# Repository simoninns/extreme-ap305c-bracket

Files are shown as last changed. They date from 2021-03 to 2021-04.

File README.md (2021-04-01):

# Extreme-AP305C-Bracket

## Overview
This project provides a 3D printable bracket for the Extreme Networks AP305C, AP410C and AP510C (aka Aerohive AP650) access points. 

Note: This project is GPLv3 open-source. The github repository for the model (containing the complete OpenSCAD project) can be found at https://github.com/simoninns/extreme-ap305c-bracket

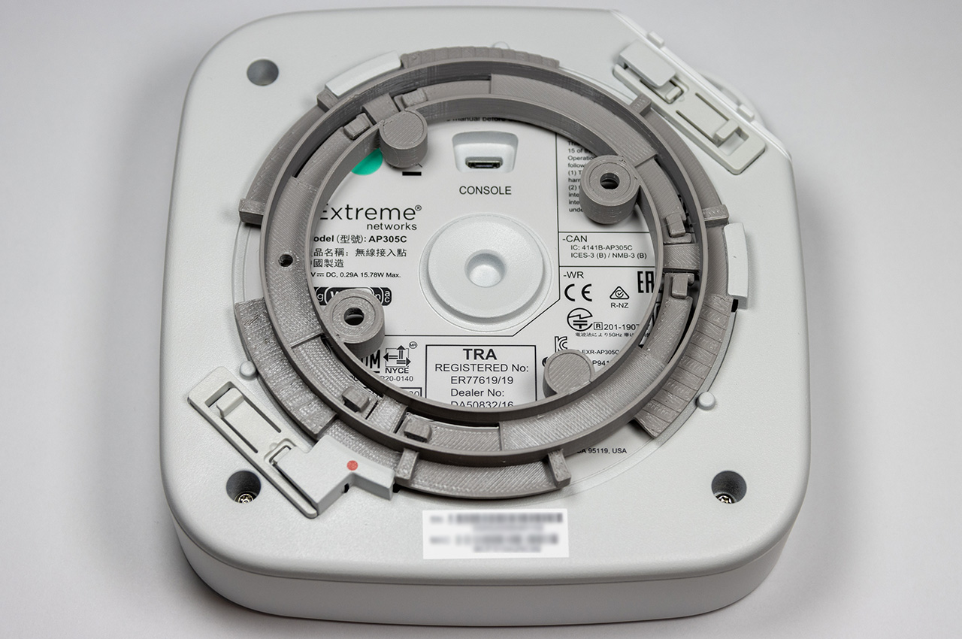
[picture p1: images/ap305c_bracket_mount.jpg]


The bracket provides two mounting points for wall or ceiling mounting using two screws (with appropriate wall plugs) which should be 3mm in diameter with 6mm flat heads.

The bracket can also be used as a desk stand for the access points (to prevent scratching of desks and other surfaces).  Attach 4x 8mm 3M Bump-on feet to the 4 marked areas to keep the bracket steady and prevent surface damage.  When used as a desk stand the bracket does not cover the console cable connector on the base of the access point.

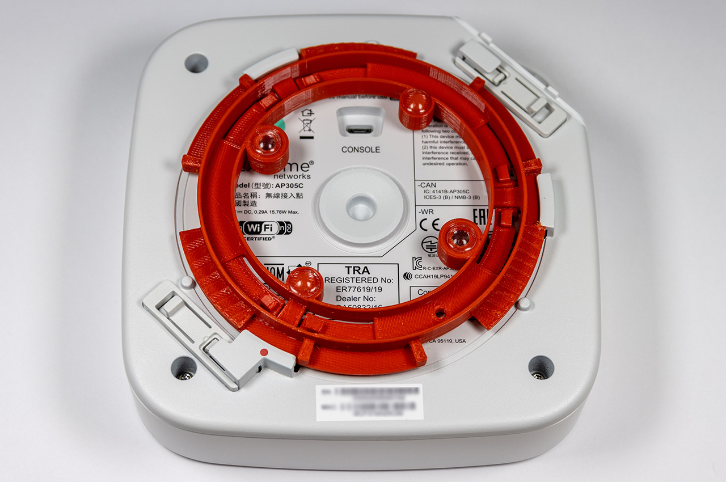
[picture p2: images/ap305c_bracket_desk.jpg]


Note that the centre line of the AP is shown as two dashes for the cable-side and one dash for the opposite.  This marked line is to assist with aligning the bracket so the network cable output is in the correct place when the bracket is orientated with the red dot on the AP.

## Printing instructions
The model has been printed and tested on the Prusa MK3S/MMU2S printer using PETG filament. All parts fit on a 20x20 printing bed.

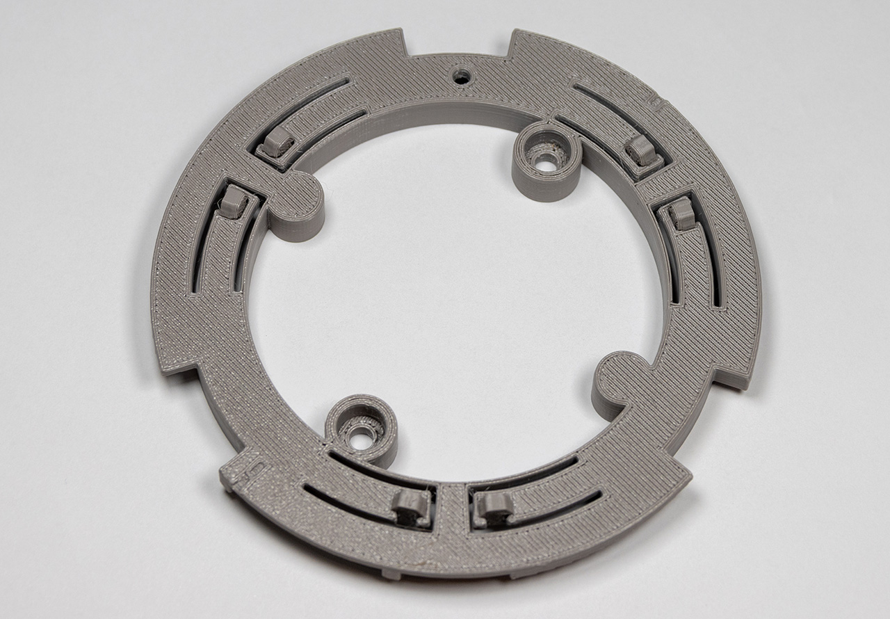
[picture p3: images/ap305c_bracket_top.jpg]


### Recommended print settings

* Material: PETG
* Layer: 0.20mm (Quality)
* Infill: 15%
* Supports: Support on build plate only
* Print time (approximate): 1h 52m

## Assembly
Place each one of the lever bumps into the lever recess sideways through the provided gap.  Twist lever bump through 90 degrees.  The bump should lock into place.  This is easier if you use a pair of small flat-nosed pliers (be careful not to squeeze the pieces too hard when handling with the pliers).

## Attaching and detaching from the AP
If the bracket is wall or ceiling mounted press down on the AP and rotate clockwise to attach and counter clockwise to detach.  If using the bracket as a desk-mount simply hold the AP in your left hand and press your right palm into the bracket to keep it flat, then rotate.

## Author
The Extreme Networks AP305C bracket is designed and maintained by Simon Inns.

## Disclaimer

Please note that this bracket is the personal work of the author.  This bracket is not associated with nor endorsed by Extreme Networks.

# Licensing

## OpenSCAD source files - software license (GPLv3)

    This is free software: you can redistribute it and/or modify
    it under the terms of the GNU General Public License as published by
    the Free Software Foundation, either version 3 of the License, or
    (at your option) any later version.
    
    This program is distributed in the hope that it will be useful,
    but WITHOUT ANY WARRANTY; without even the implied warranty of
    MERCHANTABILITY or FITNESS FOR A PARTICULAR PURPOSE.  See the
    GNU General Public License for more details.
    
    You should have received a copy of the GNU General Public License
    along with this program.  If not, see <http://www.gnu.org/licenses/>.

## Non-source-code media - Creative Commons license (Creative Commons BY-SA 4.0)

Please see the following link for details: https://creativecommons.org/licenses/by-sa/4.0/

You are free to:

Share - copy and redistribute the material in any medium or format
Adapt - remix, transform, and build upon the material
for any purpose, even commercially.

This license is acceptable for Free Cultural Works.

The licensor cannot revoke these freedoms as long as you follow the license terms.

Under the following terms:

Attribution - You must give appropriate credit, provide a link to the license, and indicate if changes were made. You may do so in any reasonable manner, but not in any way that suggests the licensor endorses you or your use.

ShareAlike - If you remix, transform, or build upon the material, you must distribute your contributions under the same license as the original.

No additional restrictions - You may not apply legal terms or technological measures that legally restrict others from doing anything the license permits.

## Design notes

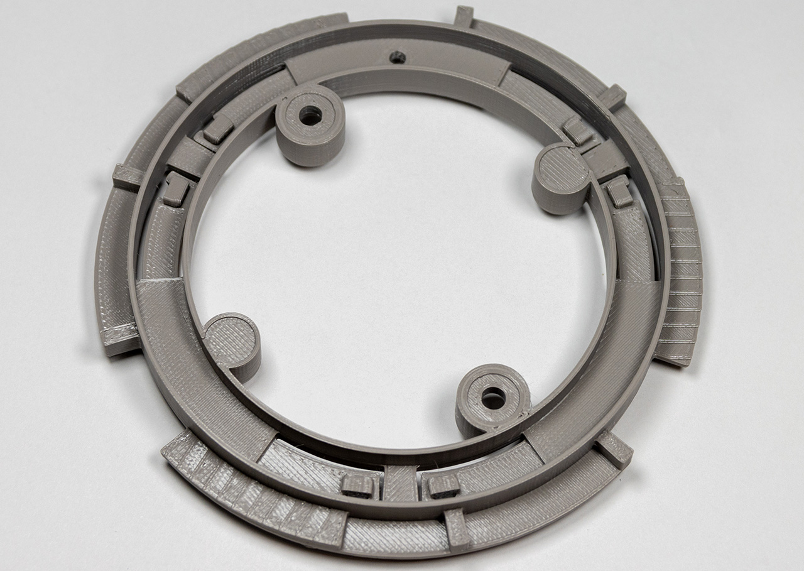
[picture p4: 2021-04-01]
images/ap305c_bracket_bottom.jpg

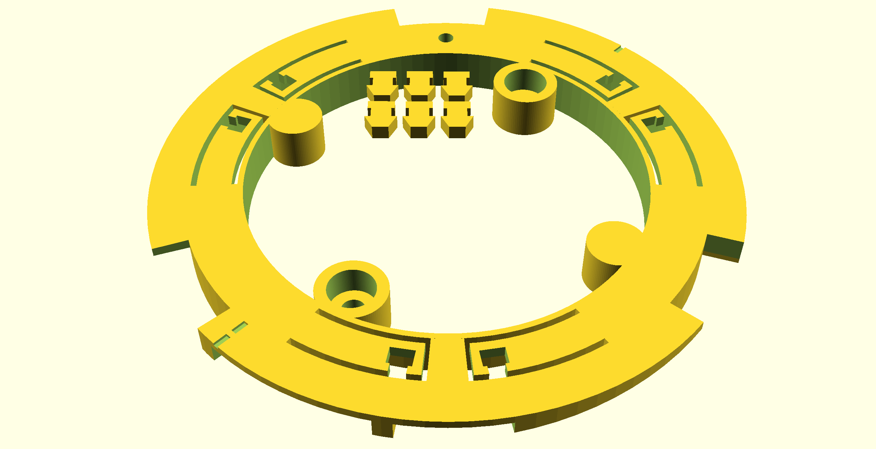
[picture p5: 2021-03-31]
images/render_top.png

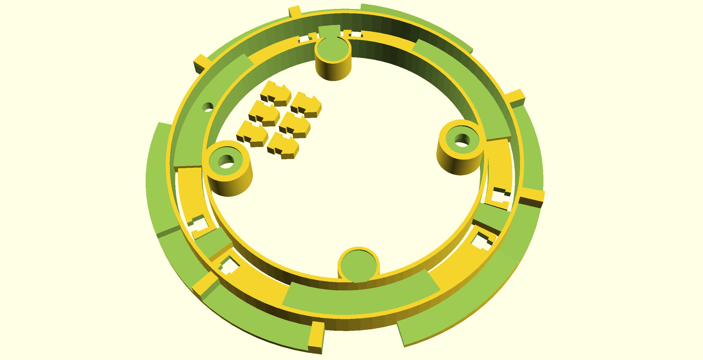
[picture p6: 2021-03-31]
images/render_bottom.png

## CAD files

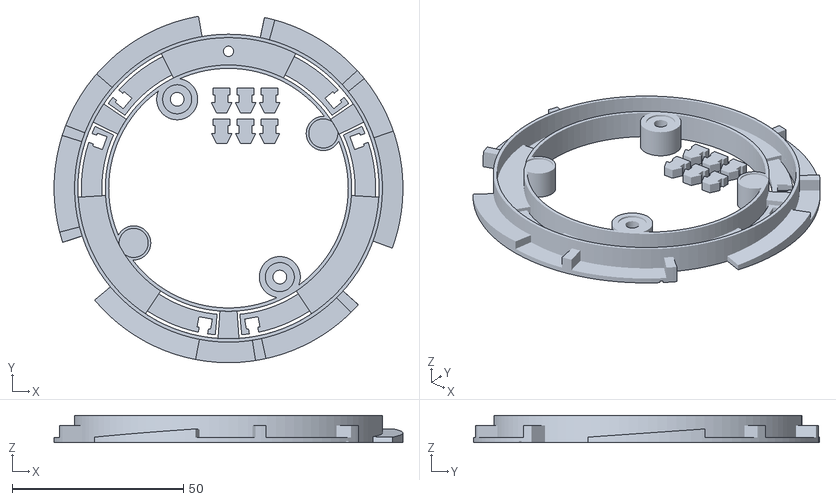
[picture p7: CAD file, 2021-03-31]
stl/extreme_ap305c_bracket.stl
102.0 x 101.2 x 8.00

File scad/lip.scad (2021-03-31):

/************************************************************************

	lip.scad
    
	Extreme Networks AP305C Bracket
    Copyright (C) 2021 Simon Inns
    
    This program is free software: you can redistribute it and/or modify
	it under the terms of the GNU General Public License as published by
	the Free Software Foundation, either version 3 of the License, or
	(at your option) any later version.
    
    This program is distributed in the hope that it will be useful,
    but WITHOUT ANY WARRANTY; without even the implied warranty of
    MERCHANTABILITY or FITNESS FOR A PARTICULAR PURPOSE.  See the
    GNU General Public License for more details.
    
    You should have received a copy of the GNU General Public License
    along with this program.  If not, see <http://www.gnu.org/licenses/>.
	
    Email: simon.inns@gmail.com
    
************************************************************************/

include <BOSL/constants.scad>
use <BOSL/transforms.scad>
use <BOSL/shapes.scad>

module solid_parts()
{
    difference() {
        union() {
            cutWidth = 37;
            rotation = 31.5;

            // Cut out 1
            rotate([0,0,0 + rotation]) {
                move([0,52,5]) rotate([90,0,0]) prismoid(size1=[cutWidth,4], size2=[0,4], h=52);
            }

            // Cut out 2
            rotate([0,0,(360/3) + rotation]) {
                move([0,52,5]) rotate([90,0,0]) prismoid(size1=[cutWidth,4], size2=[0,4], h=52);
            }

            // Cut out 3
            rotate([0,0,(-360/3) + rotation]) {
                move([0,52,5]) rotate([90,0,0]) prismoid(size1=[cutWidth,4], size2=[0,4], h=52);
            }
        }

        union() {
            cutWidth = 30;
            rotation = 31.5;

            // Cut out 1
            rotate([0,0,0 + rotation]) {
                move([0,52,4]) rotate([90,0,0]) prismoid(size1=[cutWidth,5], size2=[0,5], h=52);
            }

            // Cut out 2
            rotate([0,0,(360/3) + rotation]) {
                move([0,52,4]) rotate([90,0,0]) prismoid(size1=[cutWidth,5], size2=[0,5], h=52);
            }

            // Cut out 3
            rotate([0,0,(-360/3) + rotation]) {
                move([0,52,4]) rotate([90,0,0]) prismoid(size1=[cutWidth,5], size2=[0,5], h=52);
            }
        }

        // Inner cutout
        move([0,0,-1]) cyl(h=10, d=90, center=false);

        // Outer cutout
        move([0,0,-1]) tube(h=10, od=112, id=102);
    }   
}

module slides_cutout() 
{
    // 32mm slides
    degrees = -29;
    thickness = 4;
    twist = 4;
    height = 3.2;

    // Cut out 1
    rotate([0,twist,0 + degrees]) {
        move([0,52,height]) rotate([90,0,0]) prismoid(size1=[38,thickness], size2=[0,thickness], h=52);
    }

    // Cut out 2
    rotate([0,twist,(360/3) + degrees]) {
        move([0,52,height]) rotate([90,0,0]) prismoid(size1=[38,thickness], size2=[0,thickness], h=52);
    }

    // Cut out 3
    rotate([0,twist,(-360/3) + degrees]) {
        move([0,52,height]) rotate([90,0,0]) prismoid(size1=[38,thickness], size2=[0,thickness], h=52);
    }
}

module stops_cutout() 
{
    // 32mm slides
    degrees = 60;
    thickness = 4;
    twist = 0;
    height = 4.5;
    width = 20;

    rotate([0,twist,0 + degrees]) {
        move([0,52,height]) rotate([90,0,0]) prismoid(size1=[width,thickness], size2=[0,thickness], h=52);
    }

    // Cut out 2
    rotate([0,twist,(360/3) + degrees]) {
        move([0,52,height]) rotate([90,0,0]) prismoid(size1=[width,thickness], size2=[0,thickness], h=52);
    }

    // Cut out 3
    rotate([0,twist,(-360/3) + degrees]) {
        move([0,52,height]) rotate([90,0,0]) prismoid(size1=[width,thickness], size2=[0,thickness], h=52);
    }
}

module material_cut()
{
    union() {
        cutWidth = 30;
        rotation = 31.5;

        // Cut out 1
        rotate([0,0,0 + rotation]) {
            move([0,52,4]) rotate([90,0,0]) prismoid(size1=[cutWidth,5], size2=[0,5], h=52);
        }

        // Cut out 2
        rotate([0,0,(360/3) + rotation]) {
            move([0,52,4]) rotate([90,0,0]) prismoid(size1=[cutWidth,5], size2=[0,5], h=52);
        }

        // Cut out 3
        rotate([0,0,(-360/3) + rotation]) {
            move([0,52,4]) rotate([90,0,0]) prismoid(size1=[cutWidth,5], size2=[0,5], h=52);
        }
    }
}

module upper_lip()
{
    difference() {
        // Main outer lip
        move([0,0,4]) tube(h=4, od=102, id=90);

        // Cut out 1
        rotate([0,0,1]) {
            move([0,52,4]) rotate([90,0,0]) prismoid(size1=[20,10], size2=[0,10], h=52);
        }

        // Cut out 2
        rotate([0,0,(360/3) + 1]) {
            move([0,52,4]) rotate([90,0,0]) prismoid(size1=[20,10], size2=[0,10], h=52);
        }

        // Cut out 3
        rotate([0,0,(-360/3) + 1]) {
            move([0,52,4]) rotate([90,0,0]) prismoid(size1=[20,10], size2=[0,10], h=52);
        }

        slides_cutout();
        stops_cutout();

        material_cut();
    }
}

module lip()
{
    difference() {
        union() {
            upper_lip();
            solid_parts();
        }

        // Mark the centre across the bracket - cable side
        rotate([0,0,47]) move([-50,0,8.5]) cube([3,1,2], center=true);
        rotate([0,0,47]) move([-46,0,8.5]) cube([3,1,2], center=true);

        // Opposite side from cable
        rotate([0,0,47]) move([50,0,8.5]) cube([3,1,2], center=true);
    }
}

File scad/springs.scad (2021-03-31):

/************************************************************************

	springs.scad
    
	Extreme Networks AP305C Bracket
    Copyright (C) 2021 Simon Inns
    
    This program is free software: you can redistribute it and/or modify
	it under the terms of the GNU General Public License as published by
	the Free Software Foundation, either version 3 of the License, or
	(at your option) any later version.
    
    This program is distributed in the hope that it will be useful,
    but WITHOUT ANY WARRANTY; without even the implied warranty of
    MERCHANTABILITY or FITNESS FOR A PARTICULAR PURPOSE.  See the
    GNU General Public License for more details.
    
    You should have received a copy of the GNU General Public License
    along with this program.  If not, see <http://www.gnu.org/licenses/>.
	
    Email: simon.inns@gmail.com
    
************************************************************************/

include <BOSL/constants.scad>
use <BOSL/transforms.scad>
use <BOSL/shapes.scad>

module large_dividers()
{
    difference() {
        union() {
            rotate([0,0,0]) {
                move([0,50,4]) rotate([90,0,0]) prismoid(size1=[50,8], size2=[0,8], h=50);
            }

            rotate([0,0,360/3]) {
                move([0,50,4]) rotate([90,0,0]) prismoid(size1=[50,8], size2=[0,8], h=50);
            }

            rotate([0,0,-360/3]) {
                move([0,50,4]) rotate([90,0,0]) prismoid(size1=[50,8], size2=[0,8], h=50);
            }
        }

        // Inner cutout
        move([0,0,-2]) cyl(l=12, d=70, center=false); // should be 72

        // outer cutout
        difference() {
            move([0,0,-2]) cyl(l=12, d=120, center=false);
            move([0,0,-3]) cyl(l=14, d=88, center=false);
        }
    }
}

module small_dividers()
{
    difference() {
        union() {
            rotate([0,0,60]) {
                move([0,50,4]) rotate([90,0,0]) prismoid(size1=[7,8], size2=[0,8], h=50);
            }

            rotate([0,0,(360/3) + 60]) {
                move([0,50,4]) rotate([90,0,0]) prismoid(size1=[7,8], size2=[0,8], h=50);
            }

            rotate([0,0,(-360/3 + 60)]) {
                move([0,50,4]) rotate([90,0,0]) prismoid(size1=[7,8], size2=[0,8], h=50);
            }
        }

        // Inner cutout
        move([0,0,-2]) cyl(l=12, d=72.01, center=false);

        // outer cutout
        difference() {
            move([0,0,-2]) cyl(l=12, d=110, center=false);
            move([0,0,-3]) cyl(l=14, d=88, center=false);
        }
    }
}

module levers()
{
    difference() {
        // Render the material for the levers
        move([0,0,6]) tube(h=2, od=86, id=74);

        // Cut out the end of each lever to form a 1mm gap
        rotate([0,0,60]) {
            move([0,50,6]) rotate([90,0,0]) prismoid(size1=[9,8], size2=[0,8], h=50);
        }

        rotate([0,0,(360/3) + 60]) {
            move([0,50,6]) rotate([90,0,0]) prismoid(size1=[9,8], size2=[0,8], h=50);
        }

        rotate([0,0,(-360/3 + 60)]) {
            move([0,50,6]) rotate([90,0,0]) prismoid(size1=[9,8], size2=[0,8], h=50);
        }

        // Add a mounting hole to the end of each lever
        rotate([0,0,60]) {
            rotate([0,0, 10]) move([0,40,6]) {
                cube([4,3,10], center=true);
                move([0,2,0]) cube([2.75,2,10], center=true);
            }
            rotate([0,0,-10]) move([0,40,6]) {
                cube([4,3,10], center=true);
                move([0,2,0]) cube([2.75,2,10], center=true);
            }
        }
        rotate([0,0,(360/3) + 60]) {
            rotate([0,0, 10]) move([0,40,6]) {
                cube([4,3,10], center=true);
                move([0,2,0]) cube([2.75,2,10], center=true);
            }
            rotate([0,0,-10]) move([0,40,6]) {
                cube([4,3,10], center=true);
                move([0,2,0]) cube([2.75,2,10], center=true);
            }
        }
        rotate([0,0,(-360/3 + 60)]) {
            rotate([0,0, 10]) move([0,40,6]) {
                cube([4,3,10], center=true);
                move([0,2,0]) cube([2.75,2,10], center=true);
            }
            rotate([0,0,-10]) move([0,40,6]) {
                cube([4,3,10], center=true);
                move([0,2,0]) cube([2.75,2,10], center=true);
            }
        }
    }
}

module bump()
{
    // Shaft
    move([0,0,0.5]) cube([3.75,2.75,3.5], center=true);

    // Clips
    move([0,0,-1.25]) cube([5,2.75,2], center=true);

    // Head
    move([0,0,2]) prismoid(size1=[6,2.75], size2=[3,2.75], h=3);
}

module lever_bumps_print()
{
    move([-5,27,6.625]) {
        rotate([90,0,0]) {
            move([7,0,0]) bump();
            move([0,0,0]) bump();
            move([-7,0,0]) bump();

            move([7,0,9]) bump();
            move([0,0,9]) bump();
            move([-7,0,9]) bump();
        }
    }
}

module outer_edge()
{
    tube(h=8, od=90, id=88);
}

module springs()
{
    difference() {
        union() {
            // Large dividers
            large_dividers();

            // Small dividers
            small_dividers();

            // Draw the levers
            levers();

            // Edges
            outer_edge();
        }

        // Remove some material from underneath
        move([0,0,-3]) tube(h=8, od=88.01, id=50);

        // Red dot marker
        move([0,40,8]) cyl(h=16, d=3);
    }

    // Add the lever bumps in print position
    lever_bumps_print();
}

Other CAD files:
scad/main.scad
scad/screwmounts.scad

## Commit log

2021-03-28 Moved files around and added the BOSL submodule folder
    [main.scad]
2021-03-28 Basic shape dimensions just for draft
    [main.scad]
2021-03-28 Added more to the shape, but diameter dimensions are still a bit off
    [main.scad]
2021-03-28 Adjusted measurements - looks more accurate now for the springs
    [main.scad]
2021-03-28 Added cuts to springs
    [main.scad]
2021-03-29 Finished springs and moved functions into different files
    [centre.scad, lip.scad, springs.scad]
2021-03-29 Added more detail to outer lip
    [lip.scad, springs.scad]
2021-03-29 Split up and completed parts
    [lip.scad, main.scad, springs.scad]
2021-03-29 Removed material to speed up print and reshaped incorrect parts
    [lip.scad, main.scad, springs.scad]
2021-03-29 Added screw mounts and bump-on feet recesses
    [main.scad, screwmounts.scad, springs.scad]
2021-03-30 Clean up around levers and removed unused code
    [main.scad, screwmounts.scad, springs.scad]
2021-03-30 Clean up of code and fixes for some cut overlaps
    [centre.scad, lip.scad, main.scad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]
2021-03-30 Added spring bump headers
    [springs.scad]
2021-03-30 Fixed screw mounts and spring bumps
    [main.scad, screwmounts.scad, springs.scad]
2021-03-31 Changed lever bump dimensions - some clean up of code
    [main.scad, springs.scad]
2021-03-31 Fixed position error with lever bumps
    [springs.scad]
2021-03-31 Added STL file and updated read me
    [extreme_ap305c_bracket.stl]
2021-03-31 Added alignment markers and updated read me file
    [extreme_ap305c_bracket.stl, lip.scad]
2021-04-01 Added images of the bracket
